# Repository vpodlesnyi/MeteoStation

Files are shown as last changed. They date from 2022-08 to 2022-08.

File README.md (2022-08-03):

# MeteoStation
The PCB of a meteostation module for the smart home project.

Technical specifications:
- input power supply 12 V;
- total current consumption in an active mode 405 mAmps;
- CO2 sensor;
- temperature, pressure and humidity sensor;
- W5500 ethernet controller with SPI interface;
- main MCU STM32F103C8T6TR.

demo image
demo image

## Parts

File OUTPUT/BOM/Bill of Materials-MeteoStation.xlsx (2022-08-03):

Description | Part Number | Designator | Value | Voltage | Quantity
 | MH-Z19B | A1 |  |  | 1
 | BME280 | DD2 |  |  | 1
 |  | M1, M2, M3, M4 |  |  | 4
1.5 A, Step-Up/Down/ Inverting Switching Regulators | MC34063ADR2G | DA1 |  |  | 1
Cтабилитрон (лавинный выпрямительный диод) односторонний | SMAJ12A | VD2 |  |  | 1
EMI Suppression Filter | SDR0604- 680KL | L1 | 68мкГн |  | 1
EMI Suppression Filter | BLM18PG181SN1D | L3, L4 |  |  | 2
Ethernet - SPI | W5500 | DD1 |  |  | 1
Medium-density performance line ARM®-based 32-bit MCU with 64 or 128 KB Flash, USB, CAN, 7 timers, 2 ADCs, 9 com. interfaces | STM32F103C8T6TR | DD3 |  |  | 1
Диод Шоттки | PMEG4010BEA.115 | VD1, VD3 |  |  | 2
Кварц. генер. 32.768 МГц (HCMOS/TTL) | KXO-V97 | G1 |  |  | 1
Кварц. генер. 32.768 МГц (HCMOS/TTL) | KXO-V97 | G2 |  |  | 1
Конденсатор | GRM21AR72E472KW | C1, C12 | 4700 | 250В | 2
Конденсатор | GRM188R71C105KA12D** | C2, C3 | 1мк | 50B | 2
Конденсатор | GRM1885C1H391J | C5 | 390 | 50B | 1
Конденсатор | GRM31CR71H475KA12L | C9 | 4,7мк | 50В | 1
Конденсатор | GRM188R71H104KA93D | C10, C34, C35, C43 | 0,1мк | 50B | 4
Конденсатор | GRM188R71H103K | C11 | 0,01мк | 50B | 1
Конденсатор | GRM188R71H682K | C15, C17 | 6800 | 50B | 2
Конденсатор | GRM155R71H103K | C16, C20 | 0,01мк | 50B | 2
Конденсатор | GRM155R71H223K | C18 | 0,022мк | 50B | 1
Конденсатор | GRM21BR71C475KA73L | C19 | 4,7мк | 16В | 1
Конденсатор | GRM155R71C104KA88D | C21, C22, C23, C25, C26, C27, C28, C29, C30, C32, C36, C37, C38, C39, C40, C41, C42 | 0,1мк | 16B | 17
Конденсатор | GRM21BR72E103K | C24 | 0,01мк | 250В | 1
Конденсатор полярный | TKR221M1CE11 | C4 | 220мк | 16В | 1
Конденсатор полярный | TKR101M1VE11 | C6, C7 | 100мк | 35В | 2
Конденсатор полярный | TKR101M1VE11 | C8 | 100мк | 35В | 1
Конденсатор полярный | 293D106X9016A2TE3 | C13, C14, C31, C33 | 10мк | 16В | 4
Линейный стабилизатор напряжения, фиксированный выход | NCP3335ADM330R2G | DA2 |  |  | 1
Разъем - 2 конт. вилка |  | X4 |  |  | 1
Разъем - 4 конт. розетка | 43045-0400 | X1 |  |  | 1
Разъем - 5 конт. розетка | 53047-0510 | X3 |  |  | 1
Разъем - 6 конт. вилка | HR911105A | X2 |  |  | 1
Резистор | RC0805FR-0749R9L | R1 | 0,3 |  | 1
Резистор | RC0603FR-071KL | R2 | 1к |  | 1
Резистор | RC0603FR-073KL | R3 | 3к |  | 1
Резистор | RC0402FR-0782RL | R4, R7 | 82 |  | 2
Резистор | RC0603FR-070RL | R5, R6 | 0 |  | 2
Резистор | RC0402FR-0710KL | R8, R9, R10, R17, R19, R20, R22, R23, R24, R25, R26, R27, R29, R35, R39, R40 | 10к |  | 16
Резистор | RC0402FR-0747RL | R11, R15, R30, R31, R32, R33, R34, R36, R37, R38, R41, R42 | 47 |  | 12
Резистор | RC0402FR-0749R9L | R12, R14 | 49,9 |  | 2
Резистор | RC0402FR-0710RL | R13 | 10 |  | 1
Резистор | RC0603FR-0712K4L | R16 | 12,4к |  | 1
Резистор | RC0402FR-07330RL | R18, R21 | 330 |  | 2
Резистор | RC0603FR-071ML | R28 | 1м |  | 1
Синфазный дроссель | SRF0703-101M | L2 | 100мкГн |  | 1

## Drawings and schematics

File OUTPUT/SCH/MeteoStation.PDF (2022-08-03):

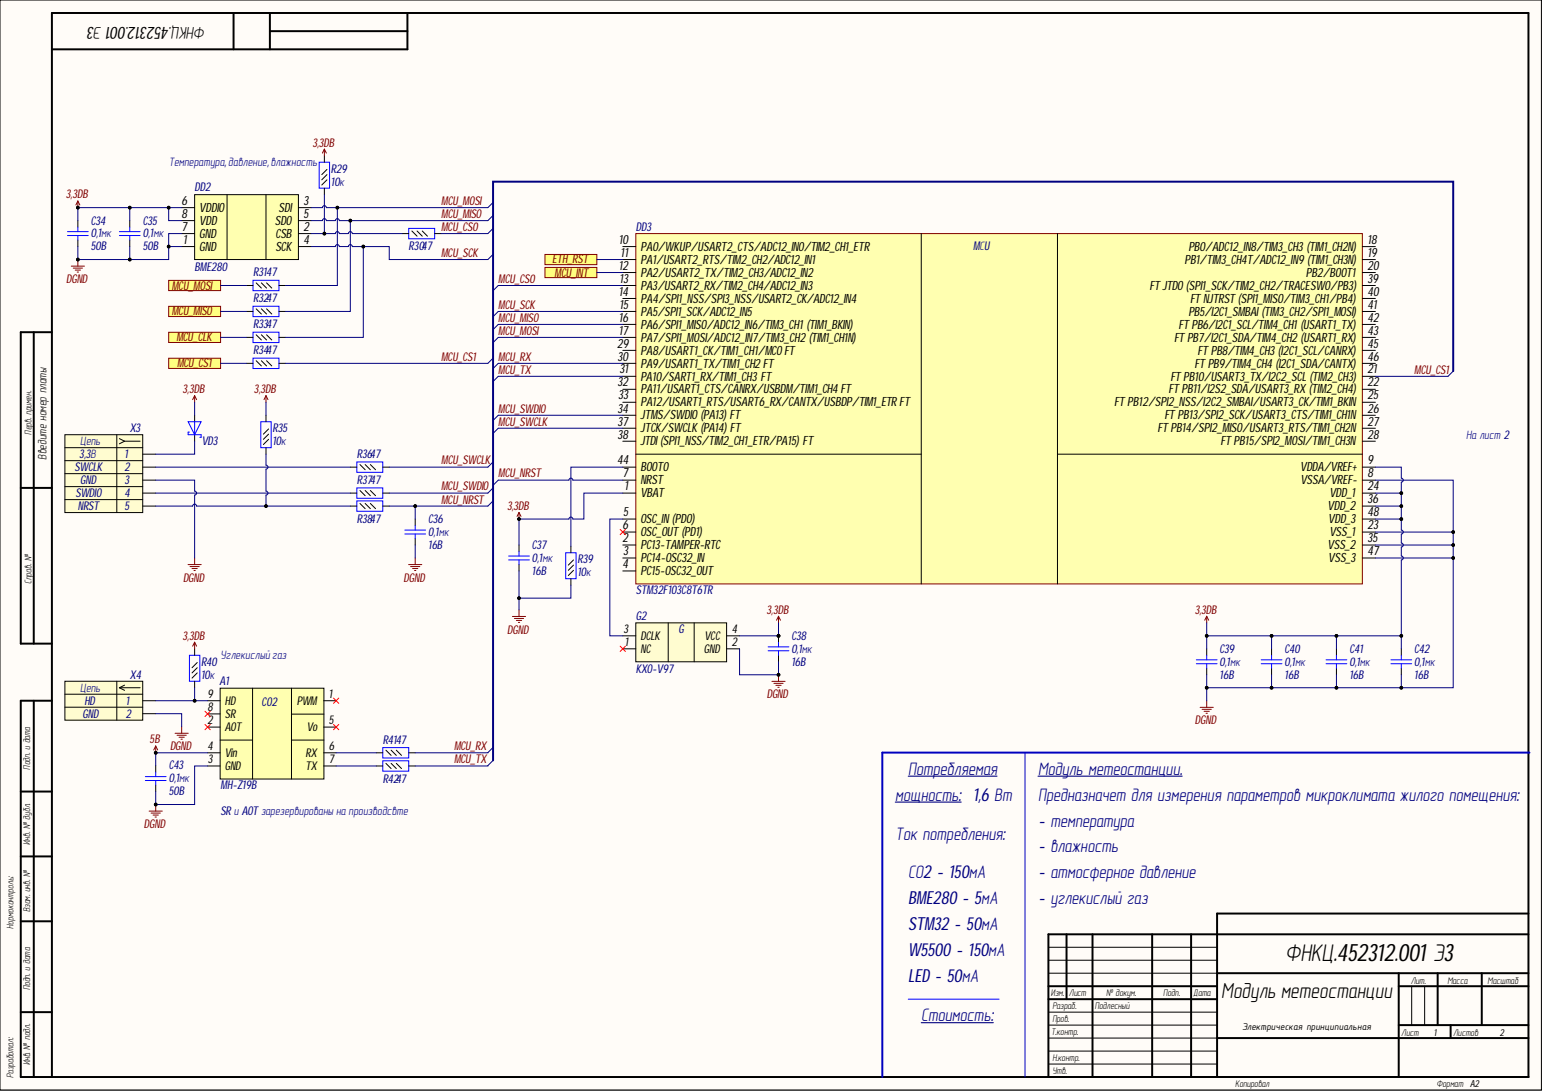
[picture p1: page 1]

Инв. № подл. Инв. № дубл. Подп. и дата Взам. инв. № Подп. и дата Перв. примен. Справ. №

3,3В | 5 X3
Цепь
SWCLK | 1234

SWDIO
NRST

2 | | 35

HD | 12
GND

Модуль метеостанции
Предназначет для измерения параметров микроклимата жилого помещения
- температура
- влажность
- атмосферное давление
- углекислый газ

ФНКЦ.452312.001 Э 3

Изм . | Лис т | № докум . | Подп . | Дат а | | | . | Масса | Масштаб 1

Модуль метеостанции Электрическая принципиальная | Лит

Разраб . | | Подлесный
Пров .
Т .контр . | | | | | Лис т | Листов 2

Н .контр .
Утв .

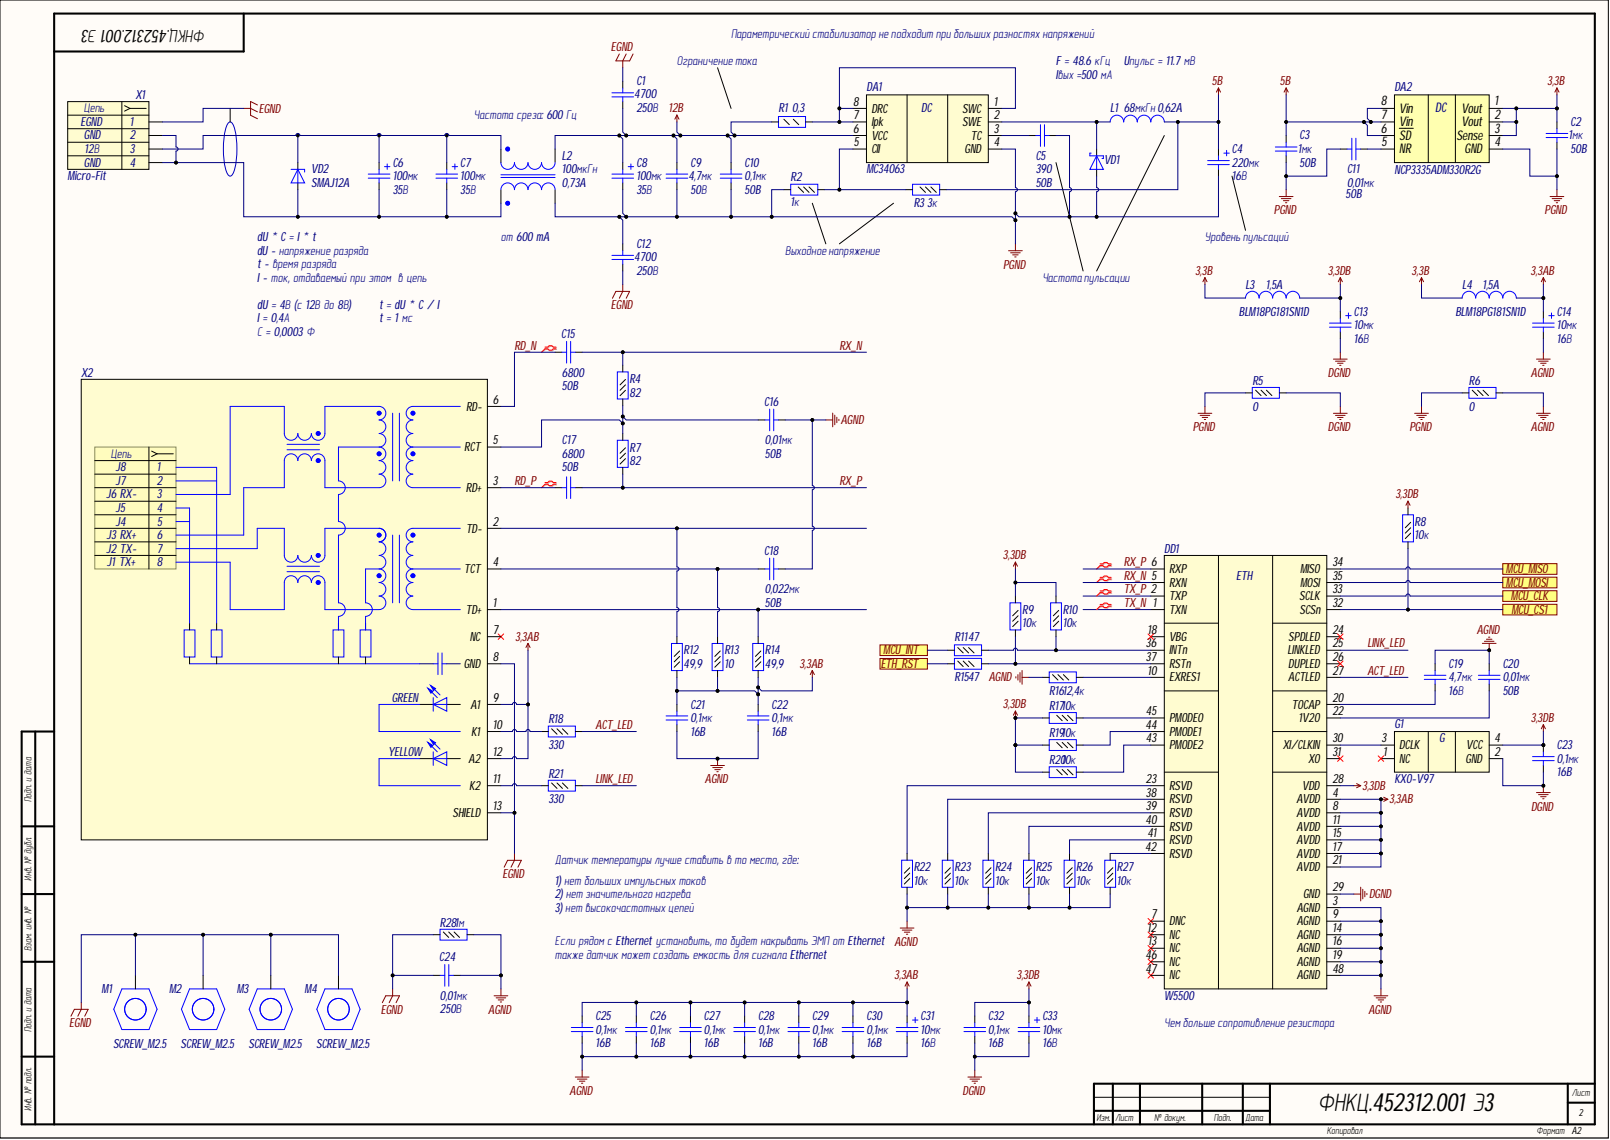
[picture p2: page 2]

Параметрический стабилизатор не подходит при больших разностях напряжений

Цепь
EGND | 1
GND | 2
12В | 3
GND | 4

dU - напряжение разряда
t - время разряда
I - ток, отдаваемый при этом в цепь

J8 | 1
J7 | 2
J6 RX- | 3
J5 | 4
J4 | 5

ФНКЦ.452312.001 Э3 в. № подл. Инв. № дубл. Подп. и дата Взам. инв. №

Датчик температуры лучше ставить в то место, где:
1) нет больших импульсных токов
2) нет значительного нагрева
3) нет высокочастотных цепей

Если рядом с Ethernet установить, то будет накрывать ЭМП от Ethernet
также датчик может создать емкость для сигнала Ethernet

Чем больше сопротивление резистора
